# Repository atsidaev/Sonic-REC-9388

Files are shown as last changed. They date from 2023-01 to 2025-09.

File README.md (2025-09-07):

# Sonic REC-9388

Sonic REC-9388 - это один из "клавиатурных" клонов Nintendo Famicom, вдохновленных Nintendo Family Basic. Построен на отдельных микросхемах CPU/PPU - UM6527 и UM6538, хотя встречается и вариант с SECAM PPU в виде впаянной на место 6538 дочерней платы, на которой расположены UM6558 и UM6559.

Эта модель Sonic получила распространение в г. Екатеринбурге и окрестностях (продавалась фирмой, расположенной в г. Верхняя Пышма). Иных каналов поставки в Россию, по-видимому, не было.

Характерной особенностью REC-9388 являются три дополнительных слота под картриджи особого (ни с чем не совместимосго) формата, на которых записаны программы, работающие с клавиатурой. Три картриджа поставлялось в комплекте с самим компьютером, о существовании каких-то либо ещё неизвестно.

В этом репозитории я собираюсь складывать имеющуюся информацию о Сонике.

## Картриджи с софтом

У меня есть парочка "ненужных" картриджей для Соника, один из них был распаян и плата отсканирована. Вот схема (неполная, только то, что вызвонилось на ногах EEPROM):

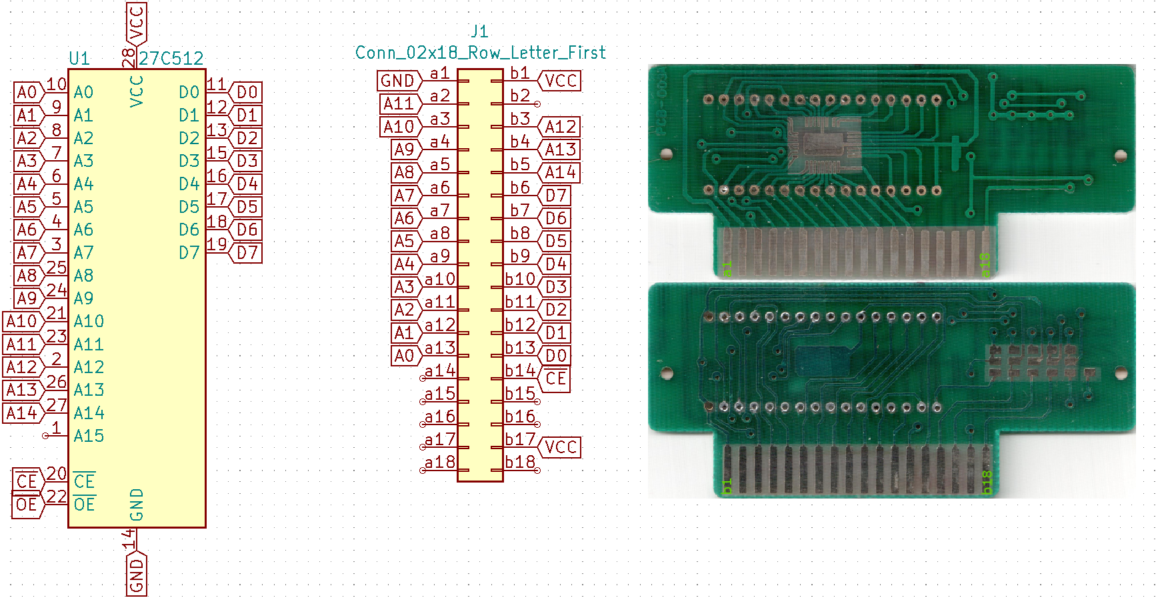
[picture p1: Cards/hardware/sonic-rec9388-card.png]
Схема картриджа


Была прочитана сама микросхема, содержимое полностью совпало с ранее полученным [здесь](https://www.emu-land.net/forum/index.php/topic,210.550.html#lastPost) (благодарности murgatroid_79, evgeny и Rumata). Мой дамп и дампы двух остальных картриджей с emu-land размещены [в этой директории](https://github.com/atsidaev/Sonic-REC-9388/tree/master/Cards/roms).

По сканам платы ([перед](https://raw.githubusercontent.com/atsidaev/Sonic-REC-9388/master/Cards/images/PCB_Front.png), [зад](https://raw.githubusercontent.com/atsidaev/Sonic-REC-9388/master/Cards/images/PCB_Back.png)) была отрисована плата (SprintLayout -> KiCAD):

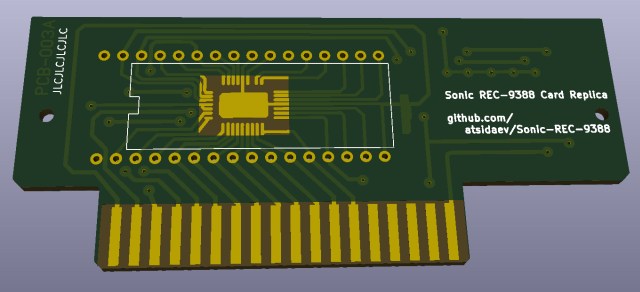
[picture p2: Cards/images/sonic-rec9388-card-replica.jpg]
Реплика платы картриджа


Платы получены, одна собрана и подтверждена работоспособность. В корпус влазят внатяг, но и оригинальные тоже сидят крайне плотно.

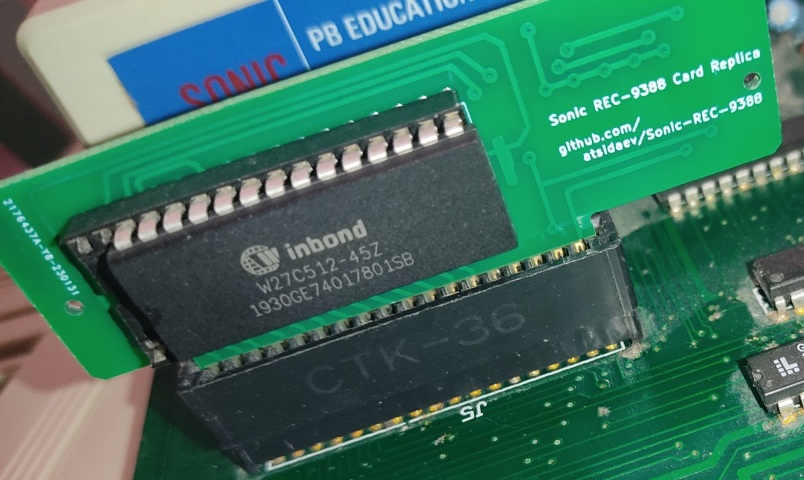
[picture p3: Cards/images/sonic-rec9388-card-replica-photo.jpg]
Фото реплики платы картриджа


## Клавиатура

Благодаря [@murgatroid79](https://github.com/murgatroid79), [пожертвовавшему свою плату](https://github.com/atsidaev/Sonic-REC-9388/issues/1) на благо реверс-инжиниринга, удалось восстановить схему клавиатуры. Kicad проект лежит [в этой директории](https://github.com/atsidaev/Sonic-REC-9388/tree/master/Keyboard/hardware). Также там есть плата, но это лишь рабочий вариант, полученный в процессе реверса, я не стремился следовать оригинальному пути дорожек и игнорировал все полигоны. Ну и, конечно, эта плата рассчитана под оригинальные кнопки, что сразу сводит на ноль её реальную полезность. Но как начальный вариант для дальнейшей переразводки под современные механические свичи вполне годится.

Схема клавиатуры достаточно оригинальна.

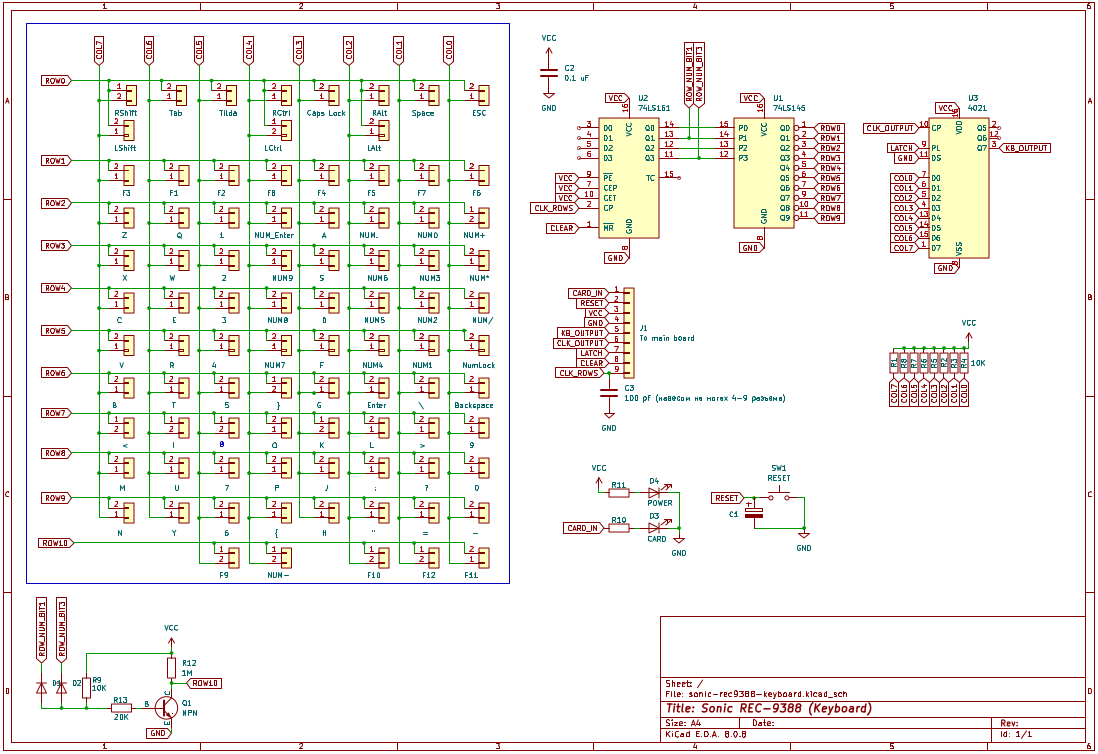
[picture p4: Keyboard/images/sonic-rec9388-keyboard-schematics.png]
Схема клавиатуры


Вместо одной 4017, как в оригинале и большинстве клонов, тут используется пара 74161 + 74145. Вероятно, это связано с тем, что создателям был нужен ряд №11, который достаточно любопытно реализован как монтажное И двух разрядов счетчика 161.

[Схема в PDF](https://raw.githubusercontent.com/atsidaev/Sonic-REC-9388/master/Keyboard/hardware/sonic-rec9388-keyboard.pdf)

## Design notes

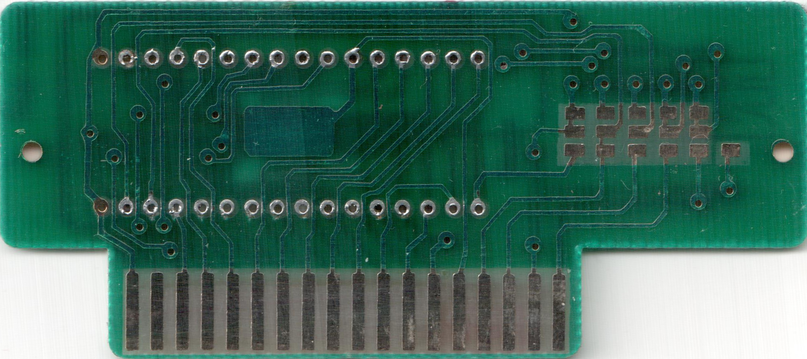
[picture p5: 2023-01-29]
Cards/images/PCB_Back.png

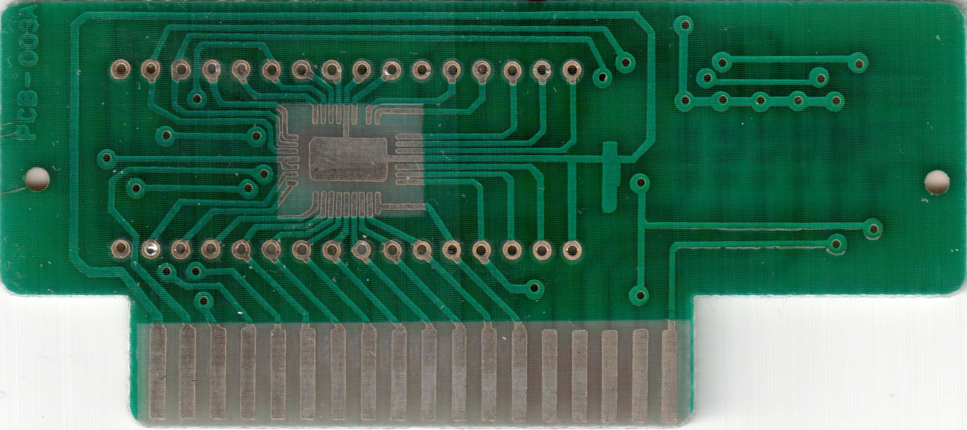
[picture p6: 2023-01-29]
Cards/images/PCB_Front.png

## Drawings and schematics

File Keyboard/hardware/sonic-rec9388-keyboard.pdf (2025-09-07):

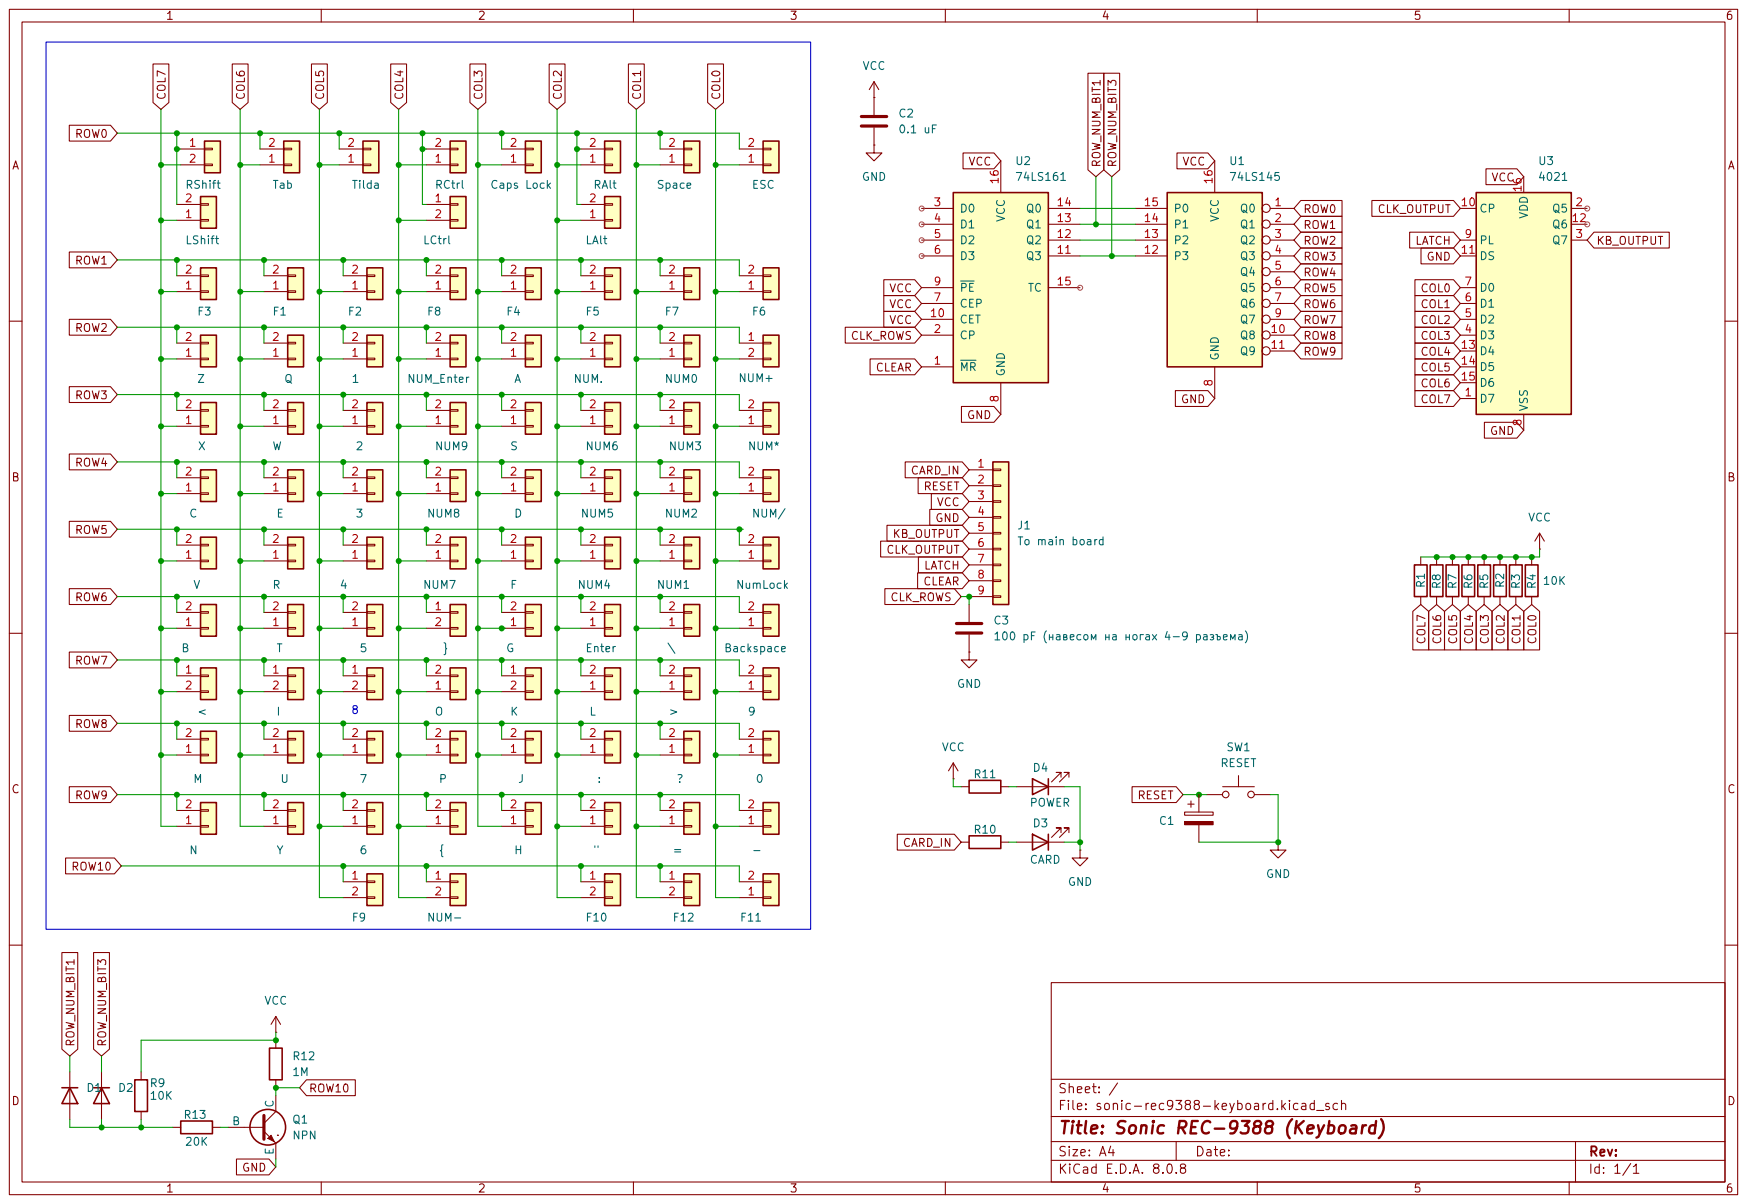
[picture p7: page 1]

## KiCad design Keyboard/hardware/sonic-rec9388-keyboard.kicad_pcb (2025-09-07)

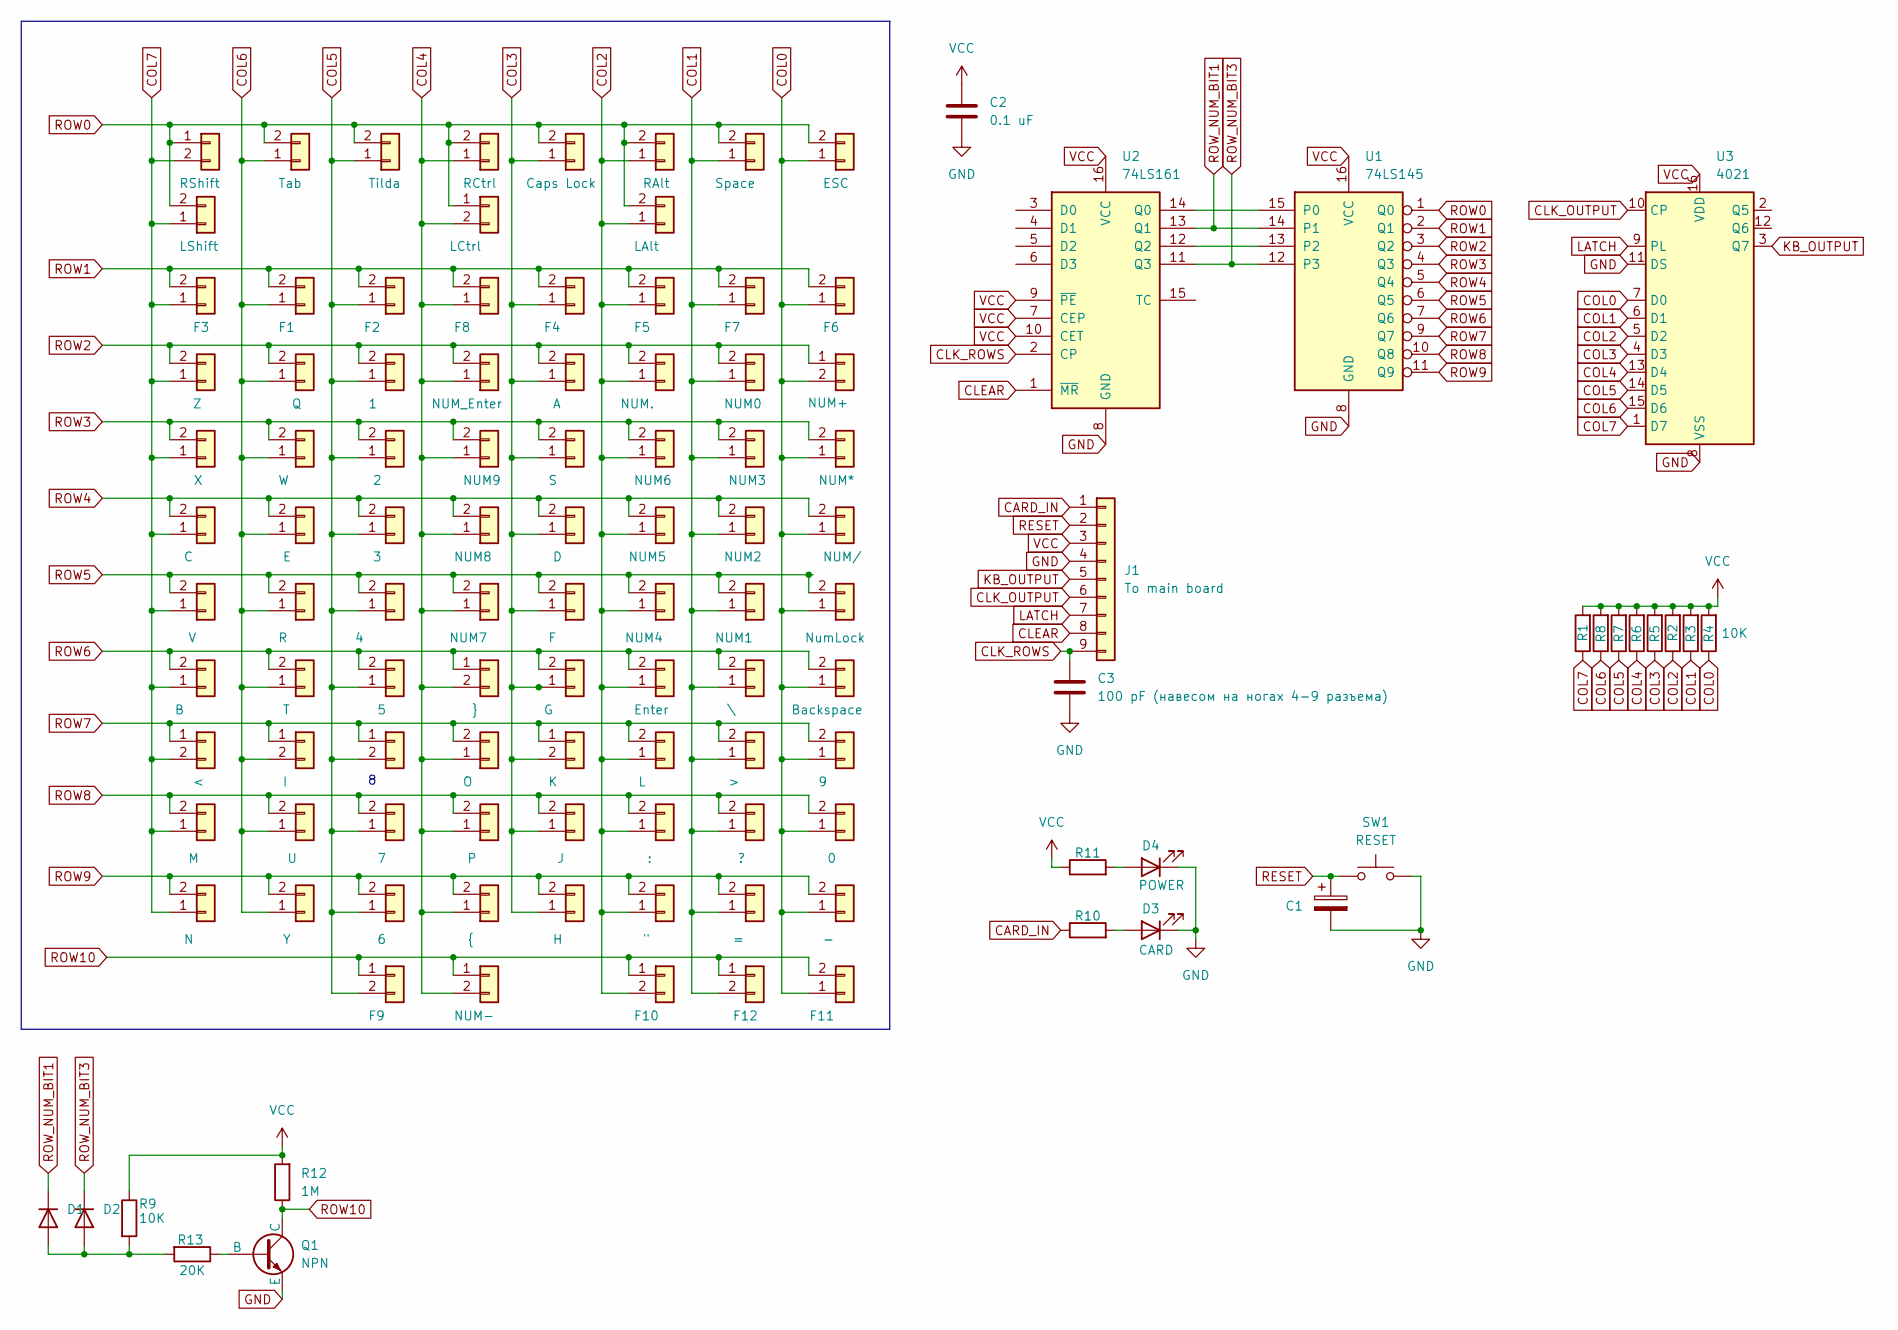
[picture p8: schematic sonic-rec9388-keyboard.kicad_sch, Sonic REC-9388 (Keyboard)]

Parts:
BTN1: >; KEYB_BUTTON
BTN2: LAlt; KEYB_BUTTON
BTN3: "; KEYB_BUTTON
BTN4: ?; KEYB_BUTTON
BTN5: E; KEYB_BUTTON
BTN6: G; KEYB_BUTTON
BTN7: }; KEYB_BUTTON
BTN8: =; KEYB_BUTTON
BTN9: -; KEYB_BUTTON
BTN10: 6; KEYB_BUTTON
BTN11: 1; KEYB_BUTTON
BTN12: <; KEYB_BUTTON
BTN13: J; KEYB_BUTTON
BTN14: Enter; KEYB_BUTTON
BTN15: H; KEYB_BUTTON
BTN16: W; KEYB_BUTTON
BTN17: F; KEYB_BUTTON
BTN18: R; KEYB_BUTTON
BTN19: {; KEYB_BUTTON
BTN20: 0; KEYB_BUTTON
BTN21: 5; KEYB_BUTTON
BTN22: F2; KEYB_BUTTON
BTN23: M; KEYB_BUTTON
BTN24: C; KEYB_BUTTON
BTN25: :; KEYB_BUTTON
BTN26: Z; KEYB_BUTTON
BTN27: Q; KEYB_BUTTON
BTN28: D; KEYB_BUTTON
BTN29: Y; KEYB_BUTTON
BTN30: P; KEYB_BUTTON
BTN31: 9; KEYB_BUTTON
BTN32: 4; KEYB_BUTTON
BTN33: Tilda; KEYB_BUTTON
BTN34: B; KEYB_BUTTON
BTN35: X; KEYB_BUTTON
BTN36: L; KEYB_BUTTON
BTN37: LShift; KEYB_BUTTON
BTN38: Tab; KEYB_BUTTON
BTN39: S; KEYB_BUTTON
BTN40: T; KEYB_BUTTON
BTN41: O; KEYB_BUTTON
BTN42: 8; KEYB_BUTTON
BTN43: 3; KEYB_BUTTON
BTN44: F1; KEYB_BUTTON
BTN45: N; KEYB_BUTTON
BTN46: V; KEYB_BUTTON
BTN47: K; KEYB_BUTTON
BTN48: LCtrl; KEYB_BUTTON
BTN49: Caps Lock; KEYB_BUTTON
BTN50: A; KEYB_BUTTON
BTN51: U; KEYB_BUTTON
BTN52: I; KEYB_BUTTON
BTN53: 7; KEYB_BUTTON
BTN54: 2; KEYB_BUTTON
BTN55: ESC; KEYB_BUTTON
BTN56: F4; KEYB_BUTTON
BTN57: F5; KEYB_BUTTON
BTN58: F8; KEYB_BUTTON
BTN59: F9; KEYB_BUTTON
BTN60: F10; KEYB_BUTTON
BTN61: F11; KEYB_BUTTON
BTN62: RCtrl; KEYB_BUTTON
BTN63: RShift; KEYB_BUTTON
BTN64: \; KEYB_BUTTON
BTN65: NUM1; KEYB_BUTTON
BTN66: NUM2; KEYB_BUTTON
BTN67: F3; KEYB_BUTTON
BTN68: F6; KEYB_BUTTON
BTN69: F7; KEYB_BUTTON
BTN70: F12; KEYB_BUTTON
BTN71: Space; KEYB_BUTTON
BTN72: RAlt; KEYB_BUTTON
BTN73: NUM0; KEYB_BUTTON
BTN74: NUM+; KEYB_BUTTON
BTN75: NUM_Enter; KEYB_BUTTON
BTN76: NUM.; KEYB_BUTTON
BTN77: NUM3; KEYB_BUTTON
BTN78: NUM-; KEYB_BUTTON
BTN79: NUM*; KEYB_BUTTON
BTN80: NUM/; KEYB_BUTTON
BTN81: NumLock; KEYB_BUTTON
BTN82: Backspace; KEYB_BUTTON
BTN83: NUM9; KEYB_BUTTON
BTN84: NUM8; KEYB_BUTTON
BTN85: NUM7; KEYB_BUTTON
BTN86: NUM6; KEYB_BUTTON
BTN87: NUM5; KEYB_BUTTON
BTN88: NUM4; KEYB_BUTTON
C1: C_Polarized; CP_Radial_D5.0mm_P2.50mm
C2: 0.1 uF; C_Rect_L9.0mm_W2.5mm_P7.50mm_MKT
C3: 100 pF (навесом на ногах 4-9 разъема); CAPACITOR-3.75
D1, D2: D; R_Axial_DIN0207_L6.3mm_D2.5mm_P10.16mm_Horizontal
D3: CARD; LED_D3.0mm
D4: POWER; LED_D3.0mm
J1: To main board; PinHeader_1x09_P2.54mm_Vertical
Q1: NPN; TO-92L_Inline_Wide
R1, R2, R3, R4, R5, R6, R7, R8, R9: 10K; R_Axial_DIN0207_L6.3mm_D2.5mm_P10.16mm_Horizontal
R10, R11: 100; R_Axial_DIN0207_L6.3mm_D2.5mm_P10.16mm_Horizontal
R12: 1M; R_Axial_DIN0207_L6.3mm_D2.5mm_P10.16mm_Horizontal
R13: 20K; R_Axial_DIN0207_L6.3mm_D2.5mm_P10.16mm_Horizontal
SW1: RESET; RESET_BTN
U1: 74LS145; DIP-16_W7.62mm_LongPads
U2: 74LS161; DIP-16_W7.62mm_LongPads
U3: 4021; DIP-16_W7.62mm_LongPads

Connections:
CARD_IN: J1.1, R10.1
CLEAR: J1.8, U2.1 (~MR)
CLK_OUTPUT: J1.6, U3.10 (CP)
CLK_ROWS: C3.1, J1.9, U2.2 (CP)
COL0: BTN9.1, BTN20.1, BTN31.1, BTN55.1, BTN61.1, BTN68.1, BTN74.2, BTN79.1, BTN80.1, BTN81.1, BTN82.1, R4.1, U3.7 (D0)
COL1: BTN1.1, BTN4.1, BTN8.1, BTN64.1, BTN65.1, BTN66.1, BTN69.1, BTN70.2, BTN71.1, BTN73.1, BTN77.1, R3.1, U3.6 (D1)
COL2: BTN2.1, BTN3.1, BTN14.1, BTN25.1, BTN36.1, BTN57.1, BTN60.2, BTN72.1, BTN76.1, BTN86.1, BTN87.1, BTN88.1, R2.1, U3.5 (D2)
COL3: BTN6.1, BTN13.1, BTN15.1, BTN17.1, BTN28.1, BTN39.1, BTN47.2, BTN49.1, BTN50.1, BTN56.1, R5.1, U3.4 (D3)
COL4: BTN7.2, BTN19.1, BTN30.1, BTN41.1, BTN48.2, BTN58.1, BTN62.1, BTN75.1, BTN78.2, BTN83.1, BTN84.1, BTN85.1, R6.1, U3.13 (D4)
COL5: BTN10.1, BTN11.1, BTN21.1, BTN22.1, BTN32.1, BTN33.1, BTN42.2, BTN43.1, BTN53.1, BTN54.1, BTN59.2, R7.1, U3.14 (D5)
COL6: BTN5.1, BTN16.1, BTN18.1, BTN27.1, BTN29.1, BTN38.1, BTN40.1, BTN44.1, BTN51.1, BTN52.2, R8.1, U3.15 (D6)
COL7: BTN12.2, BTN23.1, BTN24.1, BTN26.1, BTN34.1, BTN35.1, BTN37.1, BTN45.1, BTN46.1, BTN63.2, BTN67.1, R1.1, U3.1 (D7)
GND: C1.2, C2.2, C3.2, D3.1 (K), D4.1 (K), J1.4, Q1.3 (E), SW1.2, U1.8 (GND), U2.8 (GND), U3.8 (VSS), U3.11 (DS)
KB_OUTPUT: J1.5, U3.3 (Q7)
LATCH: J1.7, U3.9 (PL)
unnamed: D1.2 (A), D2.2 (A), R9.2, R13.2
unnamed: D3.2 (A), R10.2
unnamed: D4.2 (A), R11.2
unnamed: Q1.2 (B), R13.1
unnamed: U1.15 (P0), U2.14 (Q0)
unnamed: U1.13 (P2), U2.12 (Q2)
RESET: C1.1, J1.2, SW1.1
ROW0: BTN2.2, BTN33.2, BTN37.2, BTN38.2, BTN48.1, BTN49.2, BTN55.2, BTN62.2, BTN63.1, BTN71.2, BTN72.2, U1.1 (Q0)
ROW1: BTN22.2, BTN44.2, BTN56.2, BTN57.2, BTN58.2, BTN67.2, BTN68.2, BTN69.2, U1.2 (Q1)
ROW2: BTN11.2, BTN26.2, BTN27.2, BTN50.2, BTN73.2, BTN74.1, BTN75.2, BTN76.2, U1.3 (Q2)
ROW3: BTN16.2, BTN35.2, BTN39.2, BTN54.2, BTN77.2, BTN79.2, BTN83.2, BTN86.2, U1.4 (Q3)
ROW4: BTN5.2, BTN24.2, BTN28.2, BTN43.2, BTN66.2, BTN80.2, BTN84.2, BTN87.2, U1.5 (Q4)
ROW5: BTN17.2, BTN18.2, BTN32.2, BTN46.2, BTN65.2, BTN81.2, BTN85.2, BTN88.2, U1.6 (Q5)
ROW6: BTN6.2, BTN7.1, BTN14.2, BTN21.2, BTN34.2, BTN40.2, BTN64.2, BTN82.2, U1.7 (Q6)
ROW7: BTN1.2, BTN12.1, BTN31.2, BTN36.2, BTN41.2, BTN42.1, BTN47.1, BTN52.1, U1.9 (Q7)
ROW8: BTN4.2, BTN13.2, BTN20.2, BTN23.2, BTN25.2, BTN30.2, BTN51.2, BTN53.2, U1.10 (Q8)
ROW9: BTN3.2, BTN8.2, BTN9.2, BTN10.2, BTN15.2, BTN19.2, BTN29.2, BTN45.2, U1.11 (Q9)
ROW10: BTN59.1, BTN60.1, BTN61.2, BTN70.1, BTN78.1, Q1.1 (C), R12.1
ROW_NUM_BIT1: D1.1 (K), U1.14 (P1), U2.13 (Q1)
ROW_NUM_BIT3: D2.1 (K), U1.12 (P3), U2.11 (Q3)
VCC: C2.1, J1.3, R1.2, R2.2, R3.2, R4.2, R5.2, R6.2, R7.2, R8.2, R9.1, R11.1, R12.2, U1.16 (VCC), U2.7 (CEP), U2.9 (~PE), U2.10 (CET), U2.16 (VCC), U3.16 (VDD)

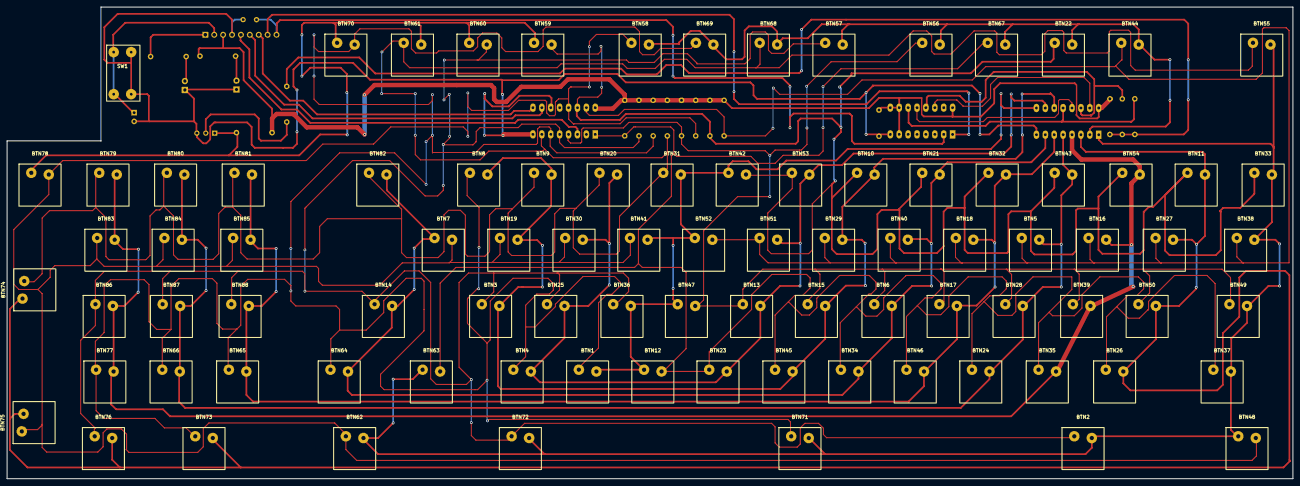
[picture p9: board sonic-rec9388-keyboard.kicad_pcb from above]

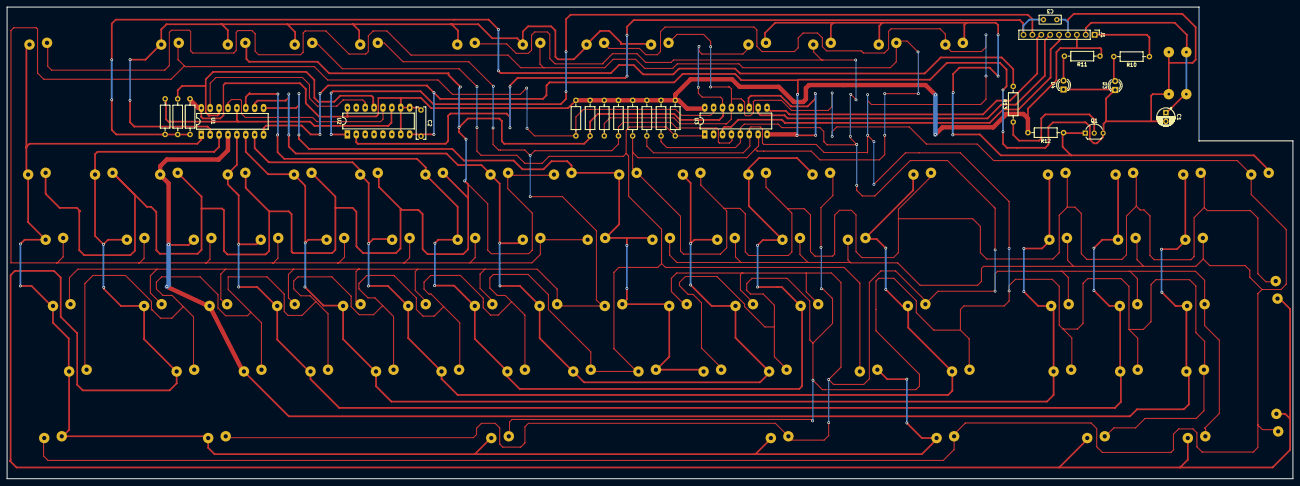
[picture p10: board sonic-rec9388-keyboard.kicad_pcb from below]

Board: 2 copper layers, 367.0 x 134.6 mm, 114 parts (25 on the bottom side), 36 nets.

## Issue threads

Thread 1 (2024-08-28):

Полный реверс Sonic-REC 9388

murgatroid79, 2024-08-28:
Приветствую.
Прежде всего хочу выразить своё восхищение проделанной Вами работой.
 Предлагаю не останавливаться и сделать реверс полностью.  У меня на руках есть полтора таких компьютера. Один полностью целый,у второго жива только основная плата, маленьких картриджей нет и клавиатура раздавлена и от корпуса мало что осталось. Я планирую эту плату распаять и сделать сканы с обоих сторон.
Латиссовские ПЛМ попробую считать на программаторе.... Но я,к сожалению,не владею программами для рисования схем и трассировки плат ☹️
 Предложения приветствуются

atsidaev, 2024-08-28:
Доброго дня!
У меня тоже полтора Соника - один почти целый (нет трех кейкапов), от второго только плата, плюс в разное время нарыл два мелких картриджа. В отрисовке схемы по плате готов поучаствовать. Но гложат меня подозрения, что на GALках включена защита чтения, и тогда их прошивку придется восстанавливать с нуля.

murgatroid79, 2025-01-05:
Привет.
Я таки,выпаял и  считал эти ПЛМ-ки 😁
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
Что-то архив с прошивками не хочет прикрепляться 😬

murgatroid79, 2025-01-05:
[ASICs.zip](https://github.com/user-attachments/files/18308999/ASICs.zip)

atsidaev, 2025-01-05:
Привет! Смотрю на дампы, и они кажутся пустыми - ни одного нуля в тех позициях, которые отвечают за входные ноги. Такое чувство, что защита все-таки включена 😟
Нули есть только в самом конце, где описывается конфигурация выходов (прямой или инверсный и т.д.)

Я поискал, и вот, например, пост про дамп защищенных GAL, и там точно такая же картина - https://cohost.org/TechRectangle/post/4829385-dumping-protected-pa

> Dumping these normally in almost any programmer results in a fuse map that's all 1s (except for the section at the end). We know this can't be correct, so the PLD must be protected.

Но тот программатор умеет вычитывать и защищенные тоже. Знать бы, как...

murgatroid79, 2025-01-05:
Хм..жалко 😕
Может эти ПЛМ-ки как ПЗУ считать...перебирать все комбинации на входных ножках и смотреть,что будет на выходе 🤔....
Надо помозговать.

atsidaev, 2025-01-05:
Два последних бита дампа - это некие SYN и AC0. Я не вдавался в подробности, но по даташиту от их комбинации зависит режим, в котором находится GALка. И у нас они, получается, SYN=0 и AC0=1, что соответствует режиму Registered Mode. Проблема в том, что в этом режиме выход идет не напрямую, а через D-триггер. То есть тут выходной сигнал зависит не просто от комбинации входных сигналов, но вдобавок еще и от внутреннего состояния самой GALки. Так что там, скорее всего, не "чистая" логическая функция, и перебором её не забрутфорсить.

atsidaev, 2025-01-07:
24-ногую микросхему выпаять оплеткой - это моё почтение 👍 Сам так не умею, я б сразу оловоотсос взял

murgatroid79, 2025-01-11:
Эмм...я не только оплёткой,ещё и феном пытался выпаять ....
Вообще демонтаж оказался очень печальным. Сначала я пытался сохранить микросхемы,но не вышло. Выводы микросхем и разъёмов со стороны пайки оказались частично "замятыми" и подрезанными как-то не аккуратно...зазубрины остались. При извлечении таких выводов был риск вырвать металлизацию из переходного отверстия. В паре мест так и произошло,и пятачки оторвались :(
   И оловоотсос в этот раз не помог...
  Тем не менее:
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
[sonic_rec-9388 top.zip](https://github.com/user-attachments/files/18386654/sonic_rec-9388.top.zip)
[sonic_rec-9388 bottom.zip](https://github.com/user-attachments/files/18386655/sonic_rec-9388.bottom.zip)

atsidaev, 2025-01-13:
Спасибо! Пятаки беда с точки зрения того, чтоб потом запаять все обратно, а для отрисовки не помешают. Тем более, что у меня же тоже есть голая плата, где сомнительные моменты всегда можно вызвонить и перепроверить.

murgatroid79, 2025-04-25:
И снова, здравствуйте 😀
Хотелось бы узнать ,есть ли какой-нибудь прогресс в отрисовке схемы?

murgatroid79, 2025-05-31:
Вау 😀
Красота!!!

murgatroid79, 2025-05-31:
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

atsidaev, 2025-06-02:
> Вот клавиатура от этого Соника.
> Собираюсь разобрать/распаять и её тоже 🤔

Распаивать, наверное, нет смысла, там же нет дорожек сверху. Можно просто снять колпачки и отследить все перемычки.
Кстати, вспомнил, что у меня лежит разобранная клавиатура от клона Family Basic, очень похожая по конструктиву на Соник. Но она именно что отдельная клавиатура для порта расширения, а не фамиклон целиком. Есть подозрение, что схемотехнически она будет идентична, любопытно.

murgatroid79, 2025-06-10:
Я, всё-таки,распаял эту клавиатуру 🙂
Причин несколько .
Сняв колпачки я обнаружил что все кнопки не только впаяны в гетинаксовую плату,они ещё "вщёлкнуты" в прямоугольные отверстия в металлической пластине,которая идёт параллельно самой плате. Перемычек видна только малая часть. Да ещё между платой и пластиной скопилась пыль и грязь,а зазор там примерно 3мм. Перемычки, конечно,можно было бы вызвонить/отследить и со стороны печати,но я решил избавится от грязи. Да и плату теперь удобнее будет вертеть.

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

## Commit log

2023-01-29 Add card PCB and Schematics
    [sonic-rec9388-card.kicad_pcb, sonic-rec9388-card.sch]
2023-01-29 Add card PCB photos
2023-01-29 Gerber added
2025-09-07 Add common Kicad custom footprints
2025-09-07 Add keyboard schematics & reversed PCB
    [sonic-rec9388-keyboard.kicad_pcb, sonic-rec9388-keyboard.kicad_sch]
2025-09-07 Update readme, add keyboard schematics
2025-09-07 Fix reset capacitor polarity
    [sonic-rec9388-keyboard.kicad_pcb, sonic-rec9388-keyboard.kicad_sch]
